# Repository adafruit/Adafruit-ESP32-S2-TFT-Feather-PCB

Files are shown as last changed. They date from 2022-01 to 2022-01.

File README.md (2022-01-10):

## Adafruit ESP32-S2 TFT Feather - 4MB Flash, 2MB PSRAM, STEMMA QT PCB

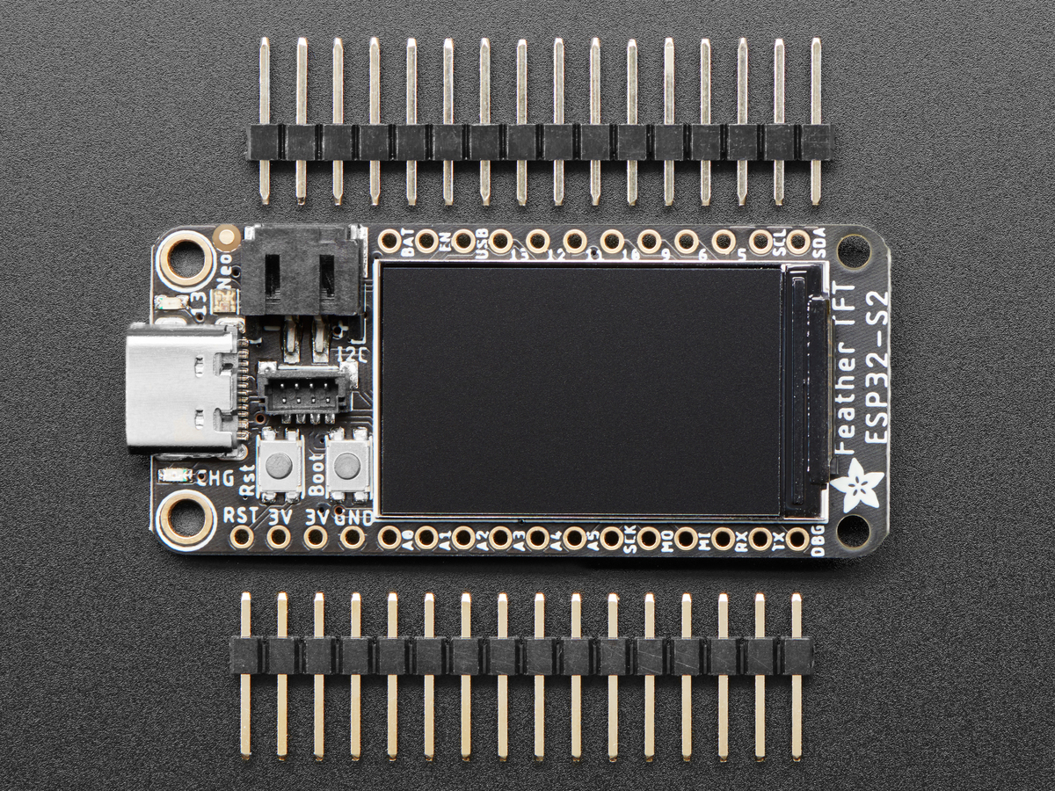
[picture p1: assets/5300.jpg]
<a href="http://www.adafruit.com/products/5300"><br/>
Click here to purchase one from the Adafruit shop</a>

PCB files for the Adafruit ESP32-S2 TFT Feather - 4MB Flash, 2MB PSRAM, STEMMA QT. 

Format is EagleCAD schematic and board layout
* https://www.adafruit.com/product/5300

### Description

We've got a new machine here at Adafruit, it can uncover your deepest desires. Don't believe me? I'll turn it on right now to prove it to you! What, you want unlimited mozzarella sticks? OK well, that's not something we can provide. But we can provide your second-deepest desire: an ESP32-S2 Feather board with a built in IPS TFT color display. It's got all the gooeyness of a mozzarella stick features of a Feather main board, the comforting warmth of an ESP32-S2 WiFi microcontroller, and the crispness of a 240x135 pixel color TFT display. All that and it will even plug in nicely into a breadboard, terminal block wing, or Feather Doubler or even just stack on top of another wing.

This feather comes with native USB and 4 MB flash + 2 MB of PSRAM, so it is perfect for use with CircuitPython or Arduino with low-cost WiFi. Native USB means it can act like a keyboard or a disk drive. WiFi means its awesome for IoT projects. And Feather means it works with the large community of Feather Wings for expandability.

The ESP32-S2 is a highly-integrated, low-power, 2.4 GHz Wi-Fi System-on-Chip (SoC) solution that now has built-in native USB as well as some other interesting new technologies like Time of Flight distance measurements. With its state-of-the-art power and RF performance, this SoC is an ideal choice for a wide variety of application scenarios relating to the Internet of Things (IoT), wearable electronics, and smart homes.

Please note the Feather ESP32-S2 has a single-core 240 MHz chip, so it won't be as fast as ESP32's with dual-core. Also, there is no Bluetooth support. However, we are super excited about the ESP32-S2's native USB which unlocks a lot of capabilities for advanced interfacing! This ESP32-S2 mini-module we are using on the Feather comes with 4 MB flash and 2 MB PSRAM so you can buffer massive JSON files for parsing!

The color TFT is connected to the SPI pins, and uses additional pins for control that are not exposed to the breakout pads. It's the same display as you see here, with 240x135 pixels and is IPS so you get bright color at any angle. The backlight is also connected to a separate pin so you can PWM the backlight up and down as desired.

For low power usages, the Feather has a second AP2112 regulator. The regulator is controlled with a GPIO pin on the enable line and can shut off power to the Stemma QT port and TFT. There is also a separate power pin for the NeoPixel that can be used to disable it for even lower quiescent power. With everything off and in deep sleep mode, the TFT feather uses about 100uA of current.

### License

Adafruit invests time and resources providing this open source design, please support Adafruit and open-source hardware by purchasing products from [Adafruit](https://www.adafruit.com)!

Designed by Limor Fried/Ladyada for Adafruit Industries.

Creative Commons Attribution/Share-Alike, all text above must be included in any redistribution. 
See license.txt for additional details.

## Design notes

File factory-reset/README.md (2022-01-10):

## Factory Reset file - ESP32-S2 TFT Feather - 4MB Flash, 2MB PSRAM, STEMMA QT

This is the factory reset file for the ESP32-S2 TFT Feather - 4MB Flash, 2MB PSRAM, STEMMA QT.

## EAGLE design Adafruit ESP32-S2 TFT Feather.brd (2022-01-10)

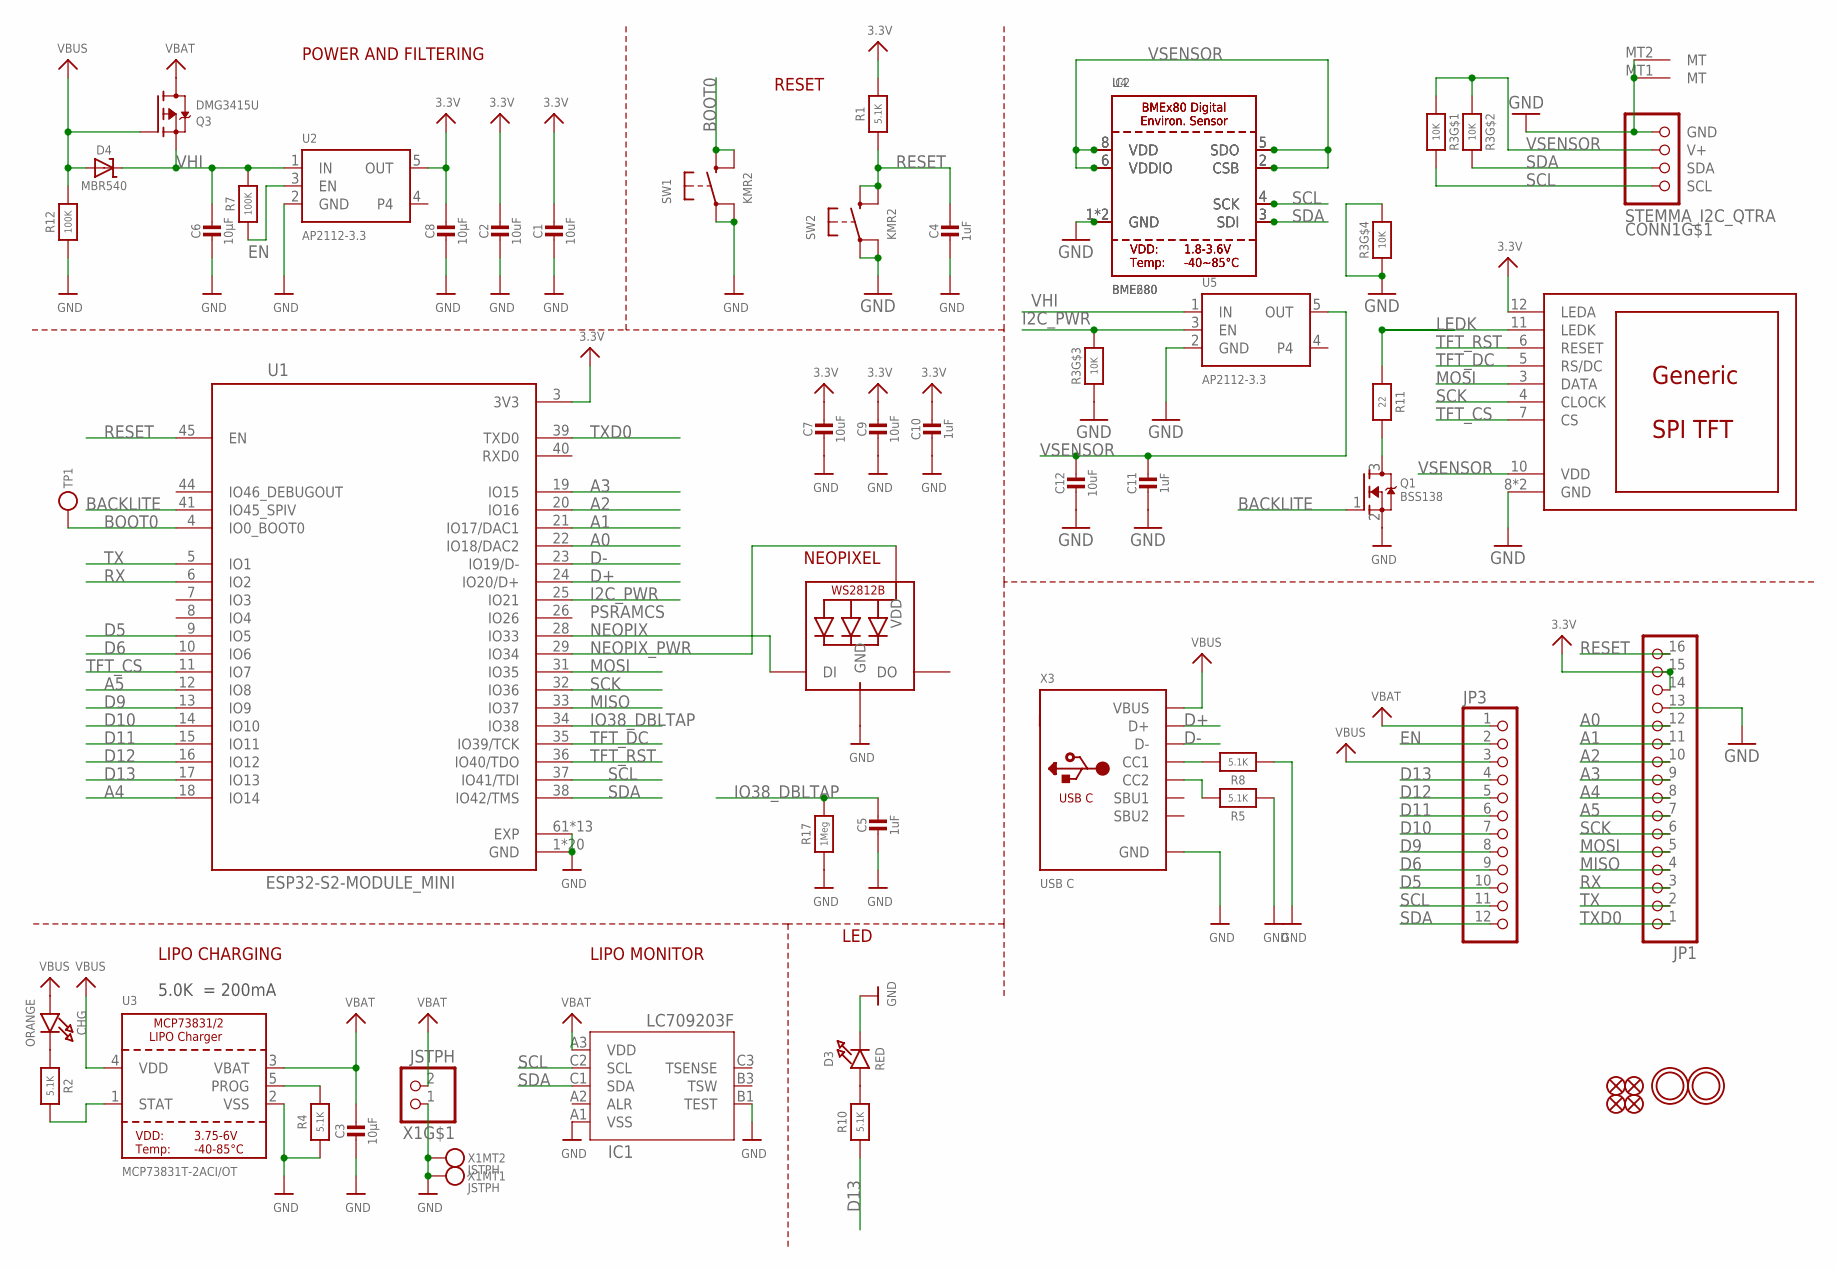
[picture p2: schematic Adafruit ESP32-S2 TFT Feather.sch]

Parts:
C1, C2, C7, C9, C12: 10uF; 0805-NO
C3, C6, C8: 10µF; 0805-NO
C4, C5, C10, C11: 1uF; 0603-NO
CHG: ORANGE; CHIPLED_0603_NOOUTLINE
CONN1: STEMMA_I2C_QTRA; JST_SH4_RA
D3: RED; CHIPLED_0603_NOOUTLINE
D4: MBR540; SOD-123
DISP1: DISP_LCD_GENERIC_SPI_1.14IN_240X135_WRAPUNDER; TFT_1.14IN_240X135_WRAPUNDER
IC1: LC709203F/MH; WLCSP9
IC2: BME680
JP1: HEADER-1X16_MIN; 1X16_ROUND_MIN
JP3: HEADER-1X12_MIN; 1X12_ROUND_MIN
LED1: WS2812B_SK6805_1515; SK6805_1515
Q1: BSS138; SOT23-R
Q3: DMG3415U; SOT23-R
R1, R2, R4, R5, R8, R10: 5.1K; 0603-NO
R3: 10K; RESPACK_4X0603
R7, R12: 100K; 0603-NO
R11: 22; 0603-NO
R17: 1Meg; 0603-NO
SW1, SW2: KMR2; BTN_KMR2_4.6X2.8
TP1: TESTPOINTROUND1.5MMNO; TESTPOINT_ROUND_1.5MM_NO
U1: ESP32-S2-MODULE_MINI; QFN60_ESP32-S2-MINI-1_EXP
U2, U5: AP2112-3.3; SOT23-5
U3: MCP73831T-2ACI/OT; SOT23-5
U4: BME280
U$31, U$32: MOUNTINGHOLE2.5; MOUNTINGHOLE_2.5_PLATED
U$34, U$35, U$55, U$56: FIDUCIAL_1MM
X1: JSTPH; JSTPH2_BATT
X3: USB C; USB_C_CUSB31-CFM2AX-01-X

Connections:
3.3V: C1.1, C2.1, C7.1, C8.1, C9.1, C10.1, DISP1.12 (LEDA), JP1.14, JP1.15, R1.2, U1.3 (3V3), U2.5 (OUT)
A0: JP1.12, U1.22 (IO18/DAC2)
A1: JP1.11, U1.21 (IO17/DAC1)
A2: JP1.10, U1.20 (IO16)
A3: JP1.9, U1.19 (IO15)
A4: JP1.8, U1.18 (IO14)
A5: JP1.7, U1.12 (IO8)
BACKLITE: Q1.1 (G), U1.41 (IO45_SPIV)
BOOT0: SW1.B (S), SW1.B' (S1), TP1.P$1, U1.4 (IO0_BOOT0)
D5: JP3.10, U1.9 (IO5)
D6: JP3.9, U1.10 (IO6)
D9: JP3.8, U1.13 (IO9)
D10: JP3.7, U1.14 (IO10)
D11: JP3.6, U1.15 (IO11)
D12: JP3.5, U1.16 (IO12)
D13: JP3.4, R10.1, U1.17 (IO13)
D+: U1.24 (IO20/D+), X3.A6 (D+), X3.B6 (D+)
D-: U1.23 (IO19/D-), X3.A7 (D-), X3.B7 (D-)
EN: JP3.2, R7.1, U2.3 (EN)
GND: C1.2, C2.2, C3.2, C4.2, C5.2, C6.2, C7.2, C8.2, C9.2, C10.2, C11.2, C12.2, CONN1.1 (GND), CONN1.MT1 (MT), CONN1.MT2 (MT), D3.C, DISP1.8 (GND), DISP1.13 (GND), IC1.A1 (VSS), IC1.B1 (TEST), IC2.1 (GND), IC2.7 (GND), JP1.13, LED1.4 (GND), Q1.2 (S), R3.3 (1), R3.4 (1), R3.5 (2), R4.1, R5.1, R8.1, R12.1, R17.1, SW1.A, SW1.A' (P1), SW2.A, SW2.A' (P1), U1.1 (GND), U1.2 (GND), U1.30 (GND), U1.42 (GND), U1.43 (GND), U1.46 (GND), U1.47 (GND), U1.48 (GND), U1.49 (GND), U1.50 (GND), U1.51 (GND), U1.52 (GND), U1.53 (GND), U1.54 (GND), U1.55 (GND), U1.56 (GND), U1.57 (GND), U1.58 (GND), U1.59 (GND), U1.60 (GND), U1.61 (EXP), U1.62 (EXP), U1.63 (EXP), U1.64 (EXP), U1.65 (EXP), U1.66 (EXP), U1.67 (EXP), U1.68 (EXP), U1.69 (EXP), U1.70 (EXP), U1.71 (EXP), U1.72 (EXP), U1.73 (EXP), U2.2 (GND), U3.2 (VSS), U4.1 (GND), U4.7 (GND), U5.2 (GND), X1.1, X1.NC1, X1.NC2, X3.A1B12 (GND), X3.B1A12 (GND)
I2C_PWR: R3.6 (2), U1.25 (IO21), U5.3 (EN)
IO38_DBLTAP: C5.1, R17.2, U1.34 (IO38)
LEDK: DISP1.11 (LEDK), R11.1
MISO: JP1.4, U1.33 (IO37)
MOSI: DISP1.3 (DATA), JP1.5, U1.31 (IO35)
unnamed: CHG.C, R2.1
unnamed: Q1.3 (D), R11.2
unnamed: R2.2, U3.1 (STAT)
unnamed: R4.2, U3.5 (PROG)
unnamed: D3.A, R10.2
unnamed: R8.2, X3.A5 (CC1)
unnamed: R5.2, X3.B5 (CC2)
NEOPIX: LED1.1 (DI), U1.28 (IO33)
NEOPIX_PWR: LED1.2 (VDD), U1.29 (IO34)
RESET: C4.1, JP1.16, R1.1, SW2.B (S), SW2.B' (S1), U1.45 (EN)
RX: JP1.3, U1.6 (IO2)
SCK: DISP1.4 (CLOCK), JP1.6, U1.32 (IO36)
SCL: CONN1.4 (SCL), IC1.C2 (SCL), IC2.4 (SCK), JP3.11, R3.8 (2), U1.37 (IO41/TDI), U4.4 (SCK)
SDA: CONN1.3 (SDA), IC1.C1 (SDA), IC2.3 (SDI), JP3.12, R3.7 (2), U1.38 (IO42/TMS), U4.3 (SDI)
TFT_CS: DISP1.7 (CS), U1.11 (IO7)
TFT_DC: DISP1.5 (RS/DC), U1.35 (IO39/TCK)
TFT_RST: DISP1.6 (RESET), U1.36 (IO40/TDO)
TX: JP1.2, U1.5 (IO1)
TXD0: JP1.1, U1.39 (TXD0)
VBAT: C3.1, IC1.A3 (VDD), JP3.1, Q3.3 (D), U3.3 (VBAT), X1.2
VBUS: CHG.A, D4.A, JP3.3, Q3.1 (G), R12.2, U3.4 (VDD), X3.A4B9 (VBUS), X3.B4A9 (VBUS)
VHI: C6.1, D4.C, Q3.2 (S), R7.2, U2.1 (IN), U5.1 (IN)
VSENSOR: C11.1, C12.1, CONN1.2 (V+), DISP1.10 (VDD), IC2.2 (CSB), IC2.5 (SDO), IC2.6 (VDDIO), IC2.8 (VDD), R3.1, R3.2 (1), U4.2 (CSB), U4.5 (SDO), U4.6 (VDDIO), U4.8 (VDD), U5.5 (OUT)

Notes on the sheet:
POWER AND FILTERING
RESET
5.0K = 200mA
LIPO CHARGING
LED
PSRAMCS
NEOPIXEL
LIPO MONITOR

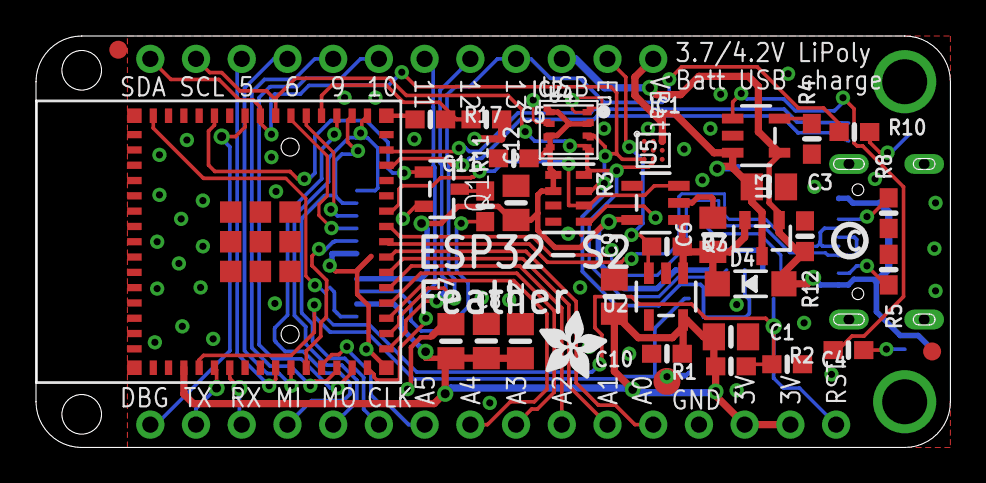
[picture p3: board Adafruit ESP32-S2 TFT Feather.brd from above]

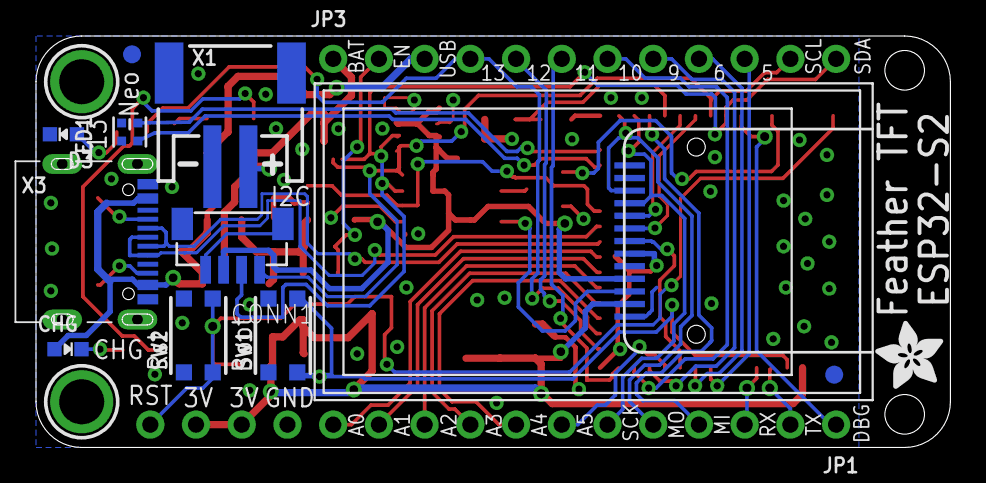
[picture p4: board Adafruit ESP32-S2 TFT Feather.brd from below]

Board: 2 copper layers, 50.8 x 22.9 mm, 54 parts (16 on the bottom side), 48 nets.

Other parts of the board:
U$7: PCBFEAT-REV-040
U$9, U$54: ADAFRUIT_3.5MM

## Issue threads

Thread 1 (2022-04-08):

What are default pins for the screen?

HaochengZheng, 2022-04-08:
In the example program, it is only stated: "Adafruit_ST7789 tft = Adafruit_ST7789(TFT_CS, TFT_DC, TFT_RST);" However I need to use the board in ESP IDF where I have to change pin assignments for CS, DC, MOSI, SCLK and RST, but I cannot find their default settings. So what are they assigned to? Thanks

ladyada, 2022-04-08:
check the schematic for absolute GPIO numbers
https://learn.adafruit.com/assets/107732

Closed 2022-04-08.

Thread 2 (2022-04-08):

Does it work with ESP-IDF?

HaochengZheng, 2022-04-08:
Maybe this is a dumb question, but does this esp32-s2 feather work with ESP-IDF? I've been trying to run some code on this product but failed. Is it only compatible with Circuit Python and Arduino?

dhalbert, 2022-04-08:
We use ESP-IDF inside CIrcuitPython and Arduino, so certainly! But there may not be a specific board definition for it? Please ask for further help in discord, https://adafru.it/discord, or in the forums: https://forums.adafruit.com.

Closed 2022-04-08.

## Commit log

2022-02-16 Updated pin name.
2023-06-22 Updating factory reset files
    Now checks for either LC or MAX battery monitor

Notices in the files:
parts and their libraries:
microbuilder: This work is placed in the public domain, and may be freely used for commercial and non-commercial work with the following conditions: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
